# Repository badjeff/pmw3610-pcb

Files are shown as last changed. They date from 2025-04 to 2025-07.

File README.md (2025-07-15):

# PMW3610 PCB

[PixArt PMW3610DM-SUDU](https://www.pixart.com/products-detail/21/PMW3610DM-SUDU) low power laser mouse sensor breakout board.

- Base on schematic from [siderakb/pmw3610-pcb](https://github.com/siderakb/pmw3610-pcb).
- Be operated with 3.3V voltage level ONLY.
- Outlined as narrow as possible for side mount horizontally and perpendicular on low profile keyboards.
- Developed for [zmk-pmw3610-driver](https://github.com/badjeff/zmk-pmw3610-driver)

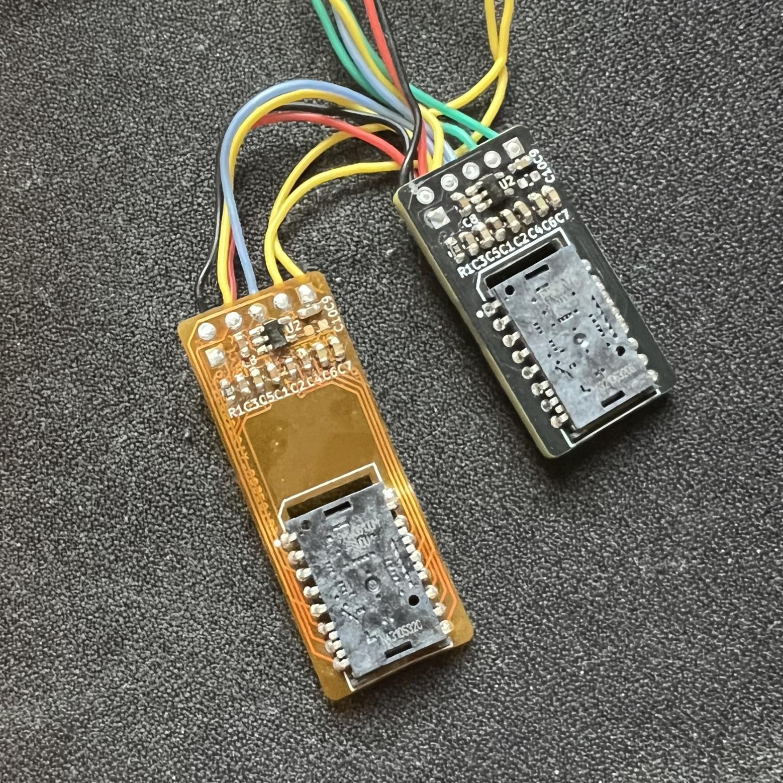
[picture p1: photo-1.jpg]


*Figure 1: Size comparing to Seeed XIAO BLE*

## PCB

Online preview avaliable [here](https://kicanvas.org/?github=https%3A%2F%2Fgithub.com%2Fbadjeff%2Fpmw3610-pcb), powered by [KiCanvas](https://github.com/theacodes/kicanvas).

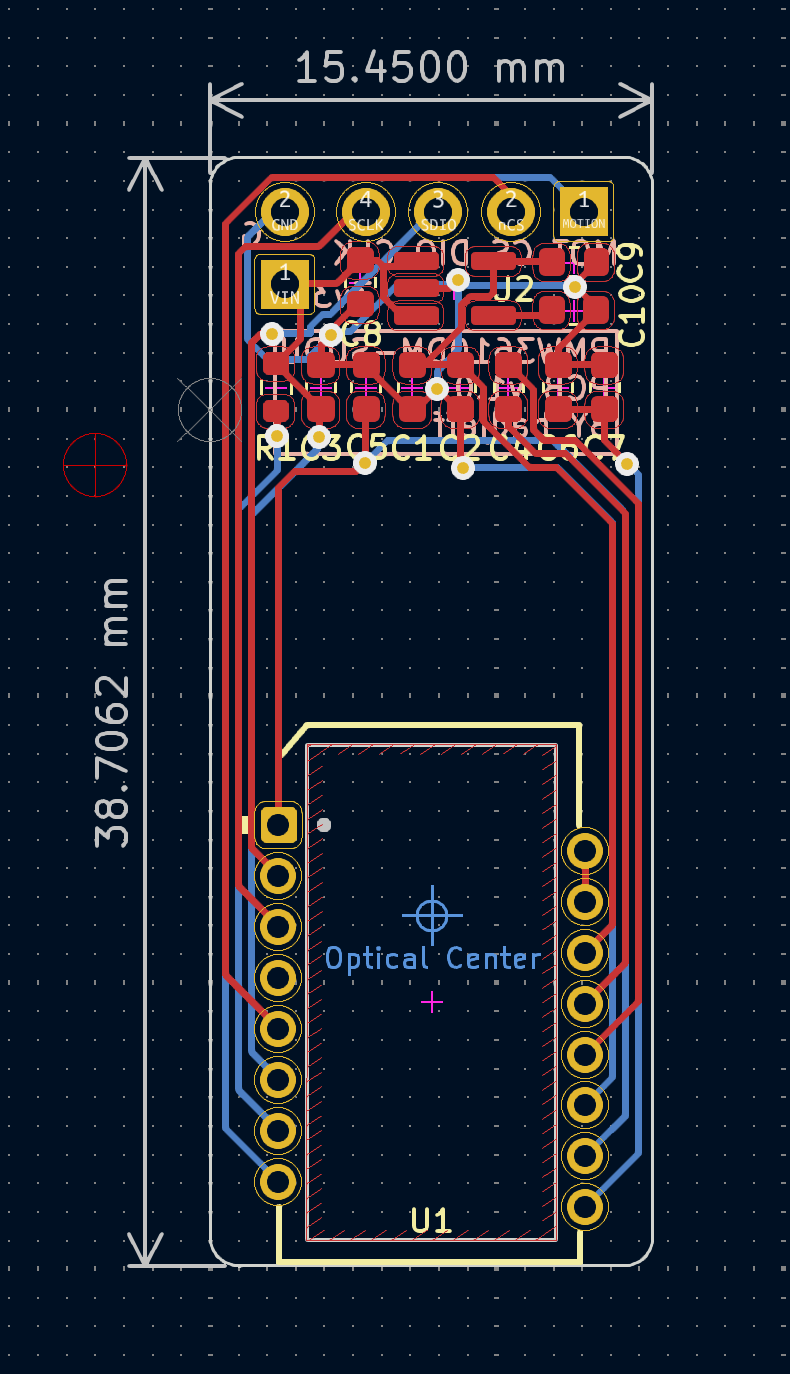
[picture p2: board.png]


*Figure 2: PCB edgecuts dimension*

### BOM

|Ref|Value|Footprint|
|-|-|-|
|C1|3.3uF/16V|SMD 0603|
|C2, C3|100nF|SMD 0603|
|C4|100nF X7R|SMD 0603|
|C5|10nF|SMD 0603|
|C6|10uF X7R|SMD 0603|
|C7|10nF X7R|SMD 0603|
|C8, C9|1uF|SMD 0603|
|C10| DNI |SMD 0603|
|R1|10k|SMD 0603|
|U1|PMW3610|16 Pin|
|U2|TLV74318|SOT-23-5|
|J1, J2|2.54mm Pin header||
- DNI: don't install.
- SMD 0603 (Imperial) aka 1608 Metric.
- PMW3610 needs to be used with LM18-LSI lens.
- `R1` is optional/additional RESET pull up resistor, RESET pin of PMW3610 has a built in weak pull up circuit.
- `U2` LDO can be replace by RT9193-18GB, change `C10` to 22nF.
- Solder extra decoupling capacitors (C4, C6, C7) directly to the pins of the sensor, if needed.

### Board Characteristics

- Copper layer count: 2
- Board thickness: 1.6 mm
- Board overall dimensions: 15.5 x 30 mm

### Voltage level config

- 3.3V logic
- VIN: 3.3V

## License

Available under the [CERN-OHL-P v2](/LICENSE) permissive license.

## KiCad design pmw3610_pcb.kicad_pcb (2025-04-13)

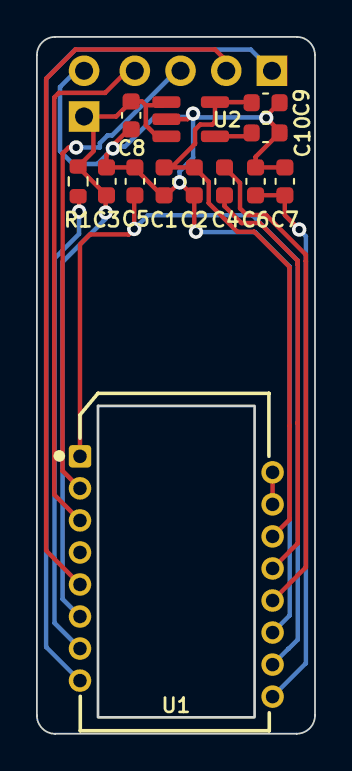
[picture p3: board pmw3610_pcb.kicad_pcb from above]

Board: 2 copper layers, 15.5 x 38.7 mm, 15 parts (0 on the bottom side), 14 nets.

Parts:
C1: 3.3uF/16V; C_0603_1608Metric
C2, C3: 100nF; C_0603_1608Metric
C4: 100nF X7R; C_0603_1608Metric
C5: 10nF; C_0603_1608Metric
C6: 10uF X7R; C_0603_1608Metric
C7: 10nF X7R; C_0603_1608Metric
C8, C9: 1uF; C_0603_1608Metric
C10: 22nF; C_0603_1608Metric
J1: Conn_01x02; PinHeader_1x02_P2.54mm_Vertical
J2: Conn_01x04; PinHeader_1x04_P2.54mm_Vertical
R1: 10k; R_0603_1608Metric
U1: PMW3610; PMW3610DM-SUDU 16Pin
U2: TLV74318PDBVR; SOT-23-5_HandSoldering

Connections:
+1V8: C1.1, C2.1, C9.1, U1.14 (VDD), U2.5 (OUT)
GND: C1.2, C2.2, C3.2, C5.2, C6.2, C7.2, C8.2, C9.2, C10.2, J1.2, U1.11 (GND), U2.2 (GND)
MOTION: J2.1, U1.8 (MOTION)
unnamed: C5.1, U1.1 (+VCSEL), U1.10 (PASS_T)
unnamed: U1.15 (XYLASER), U1.16 (-VCSEL)
unnamed: C4.2, U1.13 (CN)
unnamed: C4.1, U1.12 (CP)
unnamed: R1.2, U1.7 (NRESET)
unnamed: C6.1, C7.1, U1.9 (VCP)
unnamed: C10.1, U2.4 (NC)
SCLK: J2.4, U1.3 (SCLK)
SDIO: J2.3, U1.2 (SDIO)
VIN: C3.1, C8.1, J1.1, R1.1, U1.6 (VDDIO), U2.1 (IN), U2.3 (EN)
nCS: J2.2, U1.5 (NCS)

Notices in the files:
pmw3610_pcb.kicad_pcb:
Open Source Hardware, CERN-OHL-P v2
